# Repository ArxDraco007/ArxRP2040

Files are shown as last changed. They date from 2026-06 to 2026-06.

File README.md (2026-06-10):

# ArxRP2040 - A Custom DevBoard

## Why did I make this project?
Most devboards have limited usability. They don't fit every project. Therefore, it is best that there exists a board that is most customizable, adhering to the purposes that most projects need. This is a basic, very compact devboard that has 24 GPIO pins. This project gives a very good idea of the wiring of devboards and the parts needed to make your own.
This project can be built upon, adding additional parts, extending it, and adding the design.

## Pictures - 






## How to make it?
Follow the schematic and wire the PCB.
Use the Image Converter in KiCad to convert your images to footprints to decorate your PCB.
Download the MicroPython .uf2 file for the RP2040 from micropython.org. Hold the BOOT button (SW1) while plugging in the USB. The board appears as a USB drive. Drag and drop the .uf2 file onto it. Use Thonny IDE or any serial terminal to upload main.py
Start by applying flux to the pads on the footprint where you'll be soldering. Tin one of the pads with a small amount of solder, then carefully place your component onto the footprint. Touch your iron to the tinned pad to reflow it and tack the component in place, then let go with your tweezers once it's sitting right. Move to the opposite pad and solder it properly to the component. Finally, go back to your first pad and add a bit more solder to make sure you've got a solid joint.

## Zine!
zine

## BOM 
| Name | Purpose | Quantity | Total Cost (USD) | Link | Distributor |
|---|---|---|---|---|---|
| RP2040 | Main MCU (QFN-56) | 1 | $1.00 | [Raspberry Pi]([https://www.digikey.in/en/products/detail/raspberry-pi/SC0914/13624793](https://www.raspberrypi.com/products/rp2040/)) | Raspberry Pi |
| MCP1700x-330xxTT | 3.3V 250mA LDO regulator (SOT-23) | 1 | $0.50 | [DigiKey](https://www.digikey.in/en/products/detail/microchip-technology/MCP1700T-3302E-TT/652676) | DigiKey |
| W25Q16JVZPIQ | 16Mbit QSPI NOR Flash (WSON-8) | 1 | $0.80 | [DigiKey](https://www.digikey.in/en/products/detail/winbond-electronics/W25Q16JVZPIQ/6193781) | DigiKey |
| USB-C Receptacle 14P | HRO TYPE-C-31-M-12 or equiv | 1 | $0.50 | [Hubtronics](https://hubtronics.in/usb-c-female-port?srsltid=AfmBOop8mfonTlbqSHLuMisYp1z4lderBX-p3EpFVBi8DrW3sMfJKgY2) | Hubtronics |
| Conn_01x20 header | 2.54mm 20-pin single row (J3 and J4) | 2 | $1.00 | [Mouser](https://www.mouser.in/ProductDetail/Amphenol-FCI/67996-420HLF?qs=QKvFUfBIyQIvQWWcVN8Heg%3D%3D) | Mouser |
| Conn_01x03 header | 2.54mm 3-pin SWD debug header (J2) | 1 | $0.20 | [Robu](https://robu.in/product/ds1021-03-1x3sf11-b-connfly-1x3-pin-2-54mm-pin-header-single-row-press-fit-type/) | Robu |
| SW_Push tactile switch | BOOT/RUN button (SW1) | 1 | $0.20 | [Digikey](https://www.digikey.in/en/products/detail/alps-alpine/SKRKAEE020/19529176) | Digikey |
| Crystal 12MHz GND24 | SMD 4-pad crystal 3.2x2.5mm (Y1) | 1 | $0.50 | [ETStore](https://www.etstore.in/products/d10953) | ETStore |
| Resistor 5.1K 0402 | CC pull-downs for USB-C (R1, R2) | 2 | $0.10 | [Mouser](https://www.mouser.in/ProductDetail/Vishay-Dale/RCC04025K10FKED?qs=Imq1NPwxi76qRPANg4q4sQ%3D%3D) | Mouser |
| Resistor 27R 0402 | USB D+/D− series resistors (R3, R4) | 2 | $0.10 | [Robu](https://robu.in/product/erj2rkf27r0x-panasonic-smd-chip-resistor-27-ohm-%c2%b1-1-100-mw-0402-1005-metric-thick-film-precision/) | Robu |
| Resistor 1K 0402 | General purpose (R5, R6) | 2 | $0.10 | [Mouser](https://www.mouser.in/ProductDetail/Vishay/CRCW04021K00FHEDP?qs=Vd2sgofiCLVNiwckQwwOyw%3D%3D) | Mouser |
| Resistor 10K 0402 | Pull-up (R7) | 1 | $0.05 | [Robu](https://robu.in/product/rc0402fr-0710kl-yageo-smd-chip-resistor-10-kohm-%C2%B1-1-200-mw-0402-1005-metric-thick-film-pulse-proof-high-power-pack-of-10/) | Robu |
| Capacitor 1uF 0402 | Bulk decoupling (C1, C10) | 2 | $0.20 | [Robu](https://robu.in/product/1uf-capacitor-smdc-0402-pack-of-50/) | Robu |
| Capacitor 0.1uF 0402 | Decoupling (C2–C9, C11, C12, C17) | 11 | $0.55 | [Robu](https://robu.in/product/0402yd104kat2a-kyocera-avx-smd-multilayer-ceramic-capacitor-0-1-%C2%B5f-16-v-0402-1005-metric-%C2%B1-10-x5r-avx-0402-mlcc/) | Robu |
| Capacitor 10uF 0603 | LDO bulk caps (C13, C14) | 2 | $0.30 | [Robu](https://robu.in/product/10uf-10000nf-50v-capacitor-0603-smd-package-pack-of-5/) | Robu |
| Capacitor 33pF 0402 | Crystal load caps (C15, C16) | 2 | $0.20 | [Robu](https://robu.in/product/mc0402n330j500ct-murata-smd-multilayer-ceramic-capacitor-33-pf-50-v-0402-1005-metric-%C2%B1-5-c0g-np0-mc/) | Robu |
| PCB 2-layer ENIG | JLCPCB, 5 boards | 5 | $18.00 | [JLCPCB](https://jlcpcb.com/) | JLCPCB |
| **Total** | | | **$24.30** | | |

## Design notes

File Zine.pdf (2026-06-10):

# ARXRP2040

# ARYAN INDIA GAVASKAR

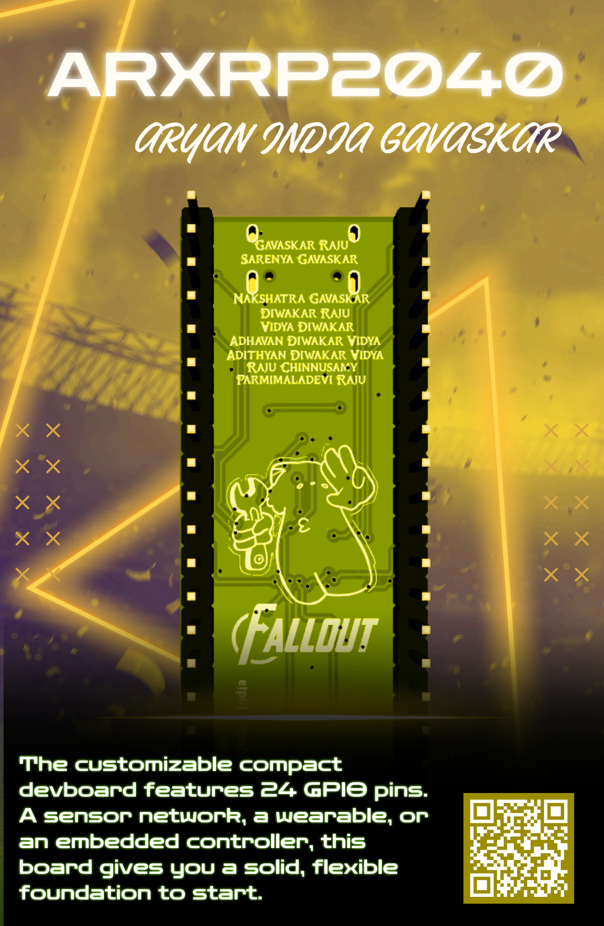
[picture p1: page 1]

The customizable compact
devboard features 24 GPIO pins. A sensor network, a wearable, or an embedded controller, this board gives you a solid, flexible foundation to start.

The customizable compact
devboard features 24 GPIO pins. A sensor network, a wearable, or an embedded controller, this board gives you a solid, flexible foundation to start.

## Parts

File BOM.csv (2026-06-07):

Name | Purpose | Quantity | Total Cost (USD) | Link | Distributor
RP2040 | Main MCU (QFN-56) | 1 | $1.00 | https://www.raspberrypi.com/products/rp2040/ | Raspberry Pi
MCP1700x-330xxTT | 3.3V 250mA LDO regulator (SOT-23) | 1 | $0.50 | https://www.digikey.in/en/products/detail/microchip-technology/MCP1700T-3302E-TT/652676 | DigiKey
W25Q16JVZPIQ | 16Mbit QSPI NOR Flash (WSON-8) | 1 | $0.80 | https://www.digikey.in/en/products/detail/winbond-electronics/W25Q16JVZPIQ/6193781 | DigiKey
USB-C Receptacle 14P | HRO TYPE-C-31-M-12 or equiv | 1 | $0.50 | https://hubtronics.in/usb-c-female-port | Hubtronics
Conn_01x20 header | 2.54mm 20-pin single row (J3 and J4) | 2 | $1.00 | https://www.mouser.in/ProductDetail/Amphenol-FCI/67996-420HLF?qs=QKvFUfBIyQIvQWWcVN8Heg%3D%3D | Mouser
Conn_01x03 header | 2.54mm 3-pin SWD debug header (J2) | 1 | $0.20 | https://robu.in/product/ds1021-03-1x3sf11-b-connfly-1x3-pin-2-54mm-pin-header-single-row-press-fit-type/ | Robu
SW_Push tactile switch | BOOT/RUN button (SW1) | 1 | $0.20 | https://www.digikey.in/en/products/detail/alps-alpine/SKRKAEE020/19529176 | Digikey
Crystal 12MHz GND24 | SMD 4-pad crystal 3.2x2.5mm (Y1) | 1 | $0.50 | https://www.etstore.in/products/d10953 | ETStore
Resistor 5.1K 0402 | CC pull-downs for USB-C (R1 R2) | 2 | $0.10 | https://www.mouser.in/ProductDetail/Vishay-Dale/RCC04025K10FKED?qs=Imq1NPwxi76qRPANg4q4sQ%3D%3D | Mouser
Resistor 27R 0402 | USB D+/D- series resistors (R3 R4) | 2 | $0.10 | https://robu.in/product/erj2rkf27r0x-panasonic-smd-chip-resistor-27-ohm | Robu
Resistor 1K 0402 | General purpose (R5 R6) | 2 | $0.10 | https://www.mouser.in/ProductDetail/Vishay/CRCW04021K00FHEDP?qs=Vd2sgofiCLVNiwckQwwOyw%3D%3D | Mouser
Resistor 10K 0402 | Pull-up (R7) | 1 | $0.05 | https://robu.in/product/rc0402fr-0710kl-yageo-smd-chip-resistor-10-kohm | Robu
Capacitor 1uF 0402 | Bulk decoupling (C1 C10) | 2 | $0.20 | https://robu.in/product/1uf-capacitor-smdc-0402-pack-of-50/ | Robu
Capacitor 0.1uF 0402 | Decoupling (C2-C9, C11, C12, C17) | 11 | $0.55 | https://robu.in/product/0402yd104kat2a-kyocera-avx-smd-multilayer-ceramic-capacitor | Robu
Capacitor 10uF 0603 | LDO bulk caps (C13 C14) | 2 | $0.30 | https://robu.in/product/10uf-10000nf-50v-capacitor-0603-smd-package-pack-of-5/ | Robu
Capacitor 33pF 0402 | Crystal load caps (C15 C16) | 2 | $0.20 | https://robu.in/product/mc0402n330j500ct-murata-smd-multilayer-ceramic-capacitor-33-pf | Robu
PCB 2-layer ENIG | JLCPCB, 5 boards | 5 | $18.00 | https://jlcpcb.com/ | JLCPCB
Total |  |  |  | $24.30

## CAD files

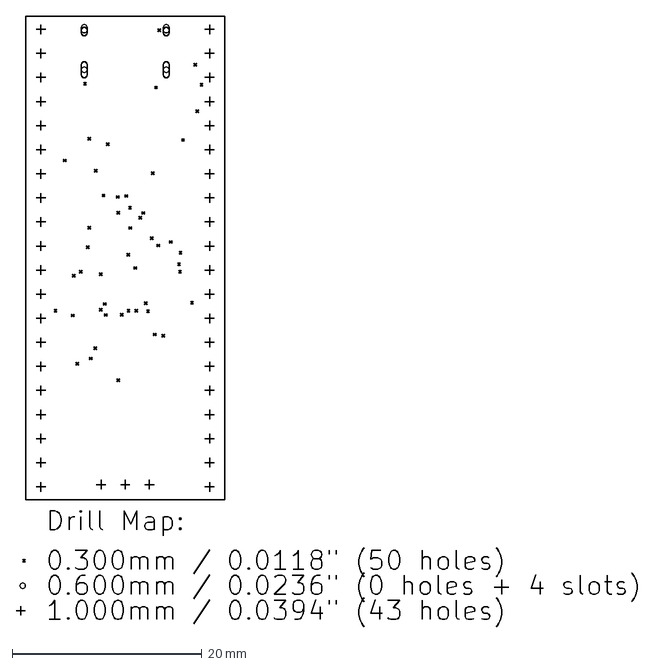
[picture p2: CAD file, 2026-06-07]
Production Files/Drill Files/ArxRP2040Devboard-PTH-drl_map.dxf
65.5 x 64.4 mm

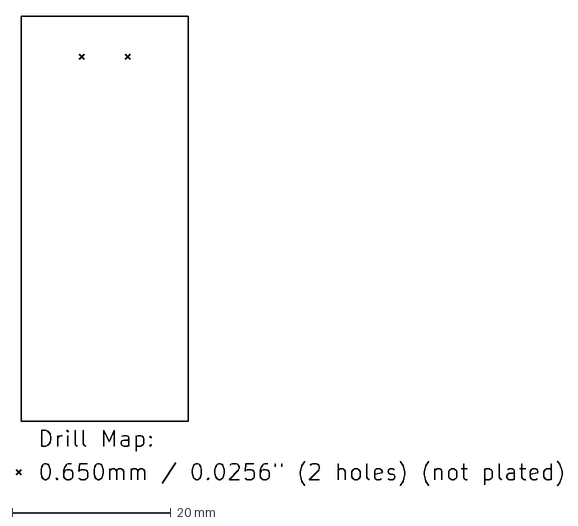
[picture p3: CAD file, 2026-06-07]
Production Files/Drill Files/ArxRP2040Devboard-NPTH-drl_map.dxf
68.8 x 59.1 mm

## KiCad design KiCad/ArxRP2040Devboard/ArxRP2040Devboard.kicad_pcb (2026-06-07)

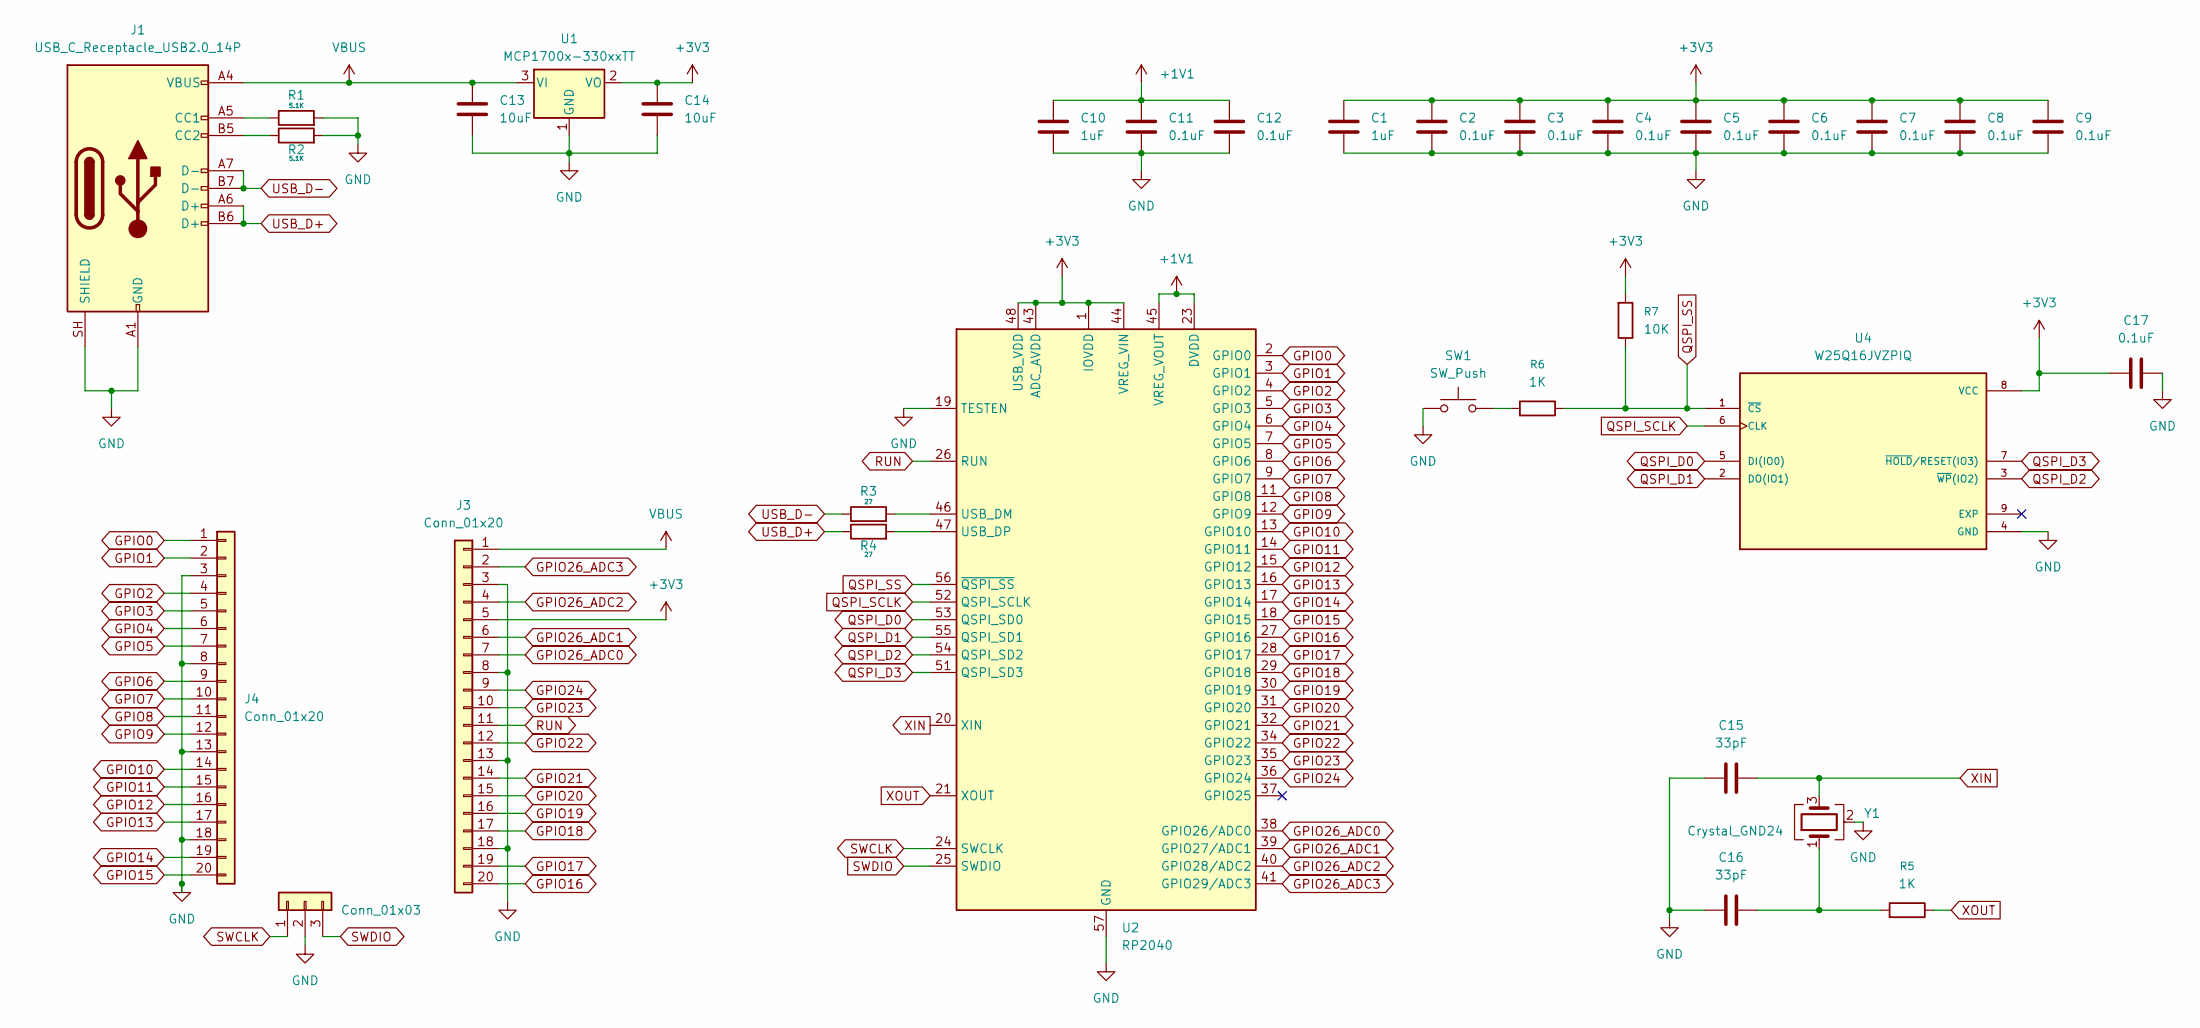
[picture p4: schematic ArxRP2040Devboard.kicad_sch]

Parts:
C1, C10: 1uF; C_0402_1005Metric
C2, C3, C4, C5, C6, C7, C8, C9, C11, C12, C17: 0.1uF; C_0402_1005Metric
C13, C14: 10uF; C_0603_1608Metric
C15, C16: 33pF; C_0402_1005Metric
J1: USB_C_Receptacle_USB2.0_14P; USB_C_Receptacle_HRO_TYPE-C-31-M-12
J2: Conn_01x03; PinHeader_1x03_P2.54mm_Vertical
J3, J4: Conn_01x20; PinHeader_1x20_P2.54mm_Vertical
R1, R2: 5.1K; R_0402_1005Metric
R3, R4: 27; R_0402_1005Metric
R5, R6: 1K; R_0402_1005Metric
R7: 10K; R_0402_1005Metric
SW1: SW_Push; SW_Push_SPST_NO_Alps_SKRK
U1: MCP1700x-330xxTT; SOT-23
U2: RP2040; QFN-56-1EP_7x7mm_P0.4mm_EP3.2x3.2mm
U4: W25Q16JVZPIQ; Winbond_USON-8-1EP_3x2mm_P0.5mm_EP0.2x1.6mm
Y1: Crystal_GND24; Crystal_SMD_3225-4Pin_3.2x2.5mm_HandSoldering

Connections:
+1V1: C10.1, C11.1, C12.1, U2.23 (DVDD), U2.45 (VREG_VOUT), U2.50 (DVDD)
+3V3: C1.1, C2.1, C3.1, C4.1, C5.1, C6.1, C7.1, C8.1, C9.1, C14.1, C17.1, J3.5, R7.1, U1.2 (VO), U2.1 (IOVDD), U2.10 (IOVDD), U2.22 (IOVDD), U2.33 (IOVDD), U2.42 (IOVDD), U2.43 (ADC_AVDD), U2.44 (VREG_VIN), U2.48 (USB_VDD), U2.49 (IOVDD), U4.8 (VCC)
GND: C1.2, C2.2, C3.2, C4.2, C5.2, C6.2, C7.2, C8.2, C9.2, C10.2, C11.2, C12.2, C13.2, C14.2, C15.1, C16.1, C17.2, J1.A1 (GND), J1.A12 (GND), J1.B1 (GND), J1.B12 (GND), J1.SH (SHIELD), J2.2, J3.3, J3.8, J3.13, J3.18, J4.3, J4.8, J4.13, J4.18, R1.2, R2.2, SW1.1, U1.1 (GND), U2.19 (TESTEN), U2.57 (GND), U4.4 (GND), Y1.2 (G), Y1.4 (G)
GPIO0: J4.1, U2.2 (GPIO0)
GPIO1: J4.2, U2.3 (GPIO1)
GPIO2: J4.4, U2.4 (GPIO2)
GPIO3: J4.5, U2.5 (GPIO3)
GPIO4: J4.6, U2.6 (GPIO4)
GPIO5: J4.7, U2.7 (GPIO5)
GPIO6: J4.9, U2.8 (GPIO6)
GPIO7: J4.10, U2.9 (GPIO7)
GPIO8: J4.11, U2.11 (GPIO8)
GPIO9: J4.12, U2.12 (GPIO9)
GPIO10: J4.14, U2.13 (GPIO10)
GPIO11: J4.15, U2.14 (GPIO11)
GPIO12: J4.16, U2.15 (GPIO12)
GPIO13: J4.17, U2.16 (GPIO13)
GPIO14: J4.19, U2.17 (GPIO14)
GPIO15: J4.20, U2.18 (GPIO15)
GPIO16: J3.20, U2.27 (GPIO16)
GPIO17: J3.19, U2.28 (GPIO17)
GPIO18: J3.17, U2.29 (GPIO18)
GPIO19: J3.16, U2.30 (GPIO19)
GPIO20: J3.15, U2.31 (GPIO20)
GPIO21: J3.14, U2.32 (GPIO21)
GPIO22: J3.12, U2.34 (GPIO22)
GPIO23: J3.10, U2.35 (GPIO23)
GPIO24: J3.9, U2.36 (GPIO24)
GPIO26_ADC0: J3.7, U2.38 (GPIO26/ADC0)
GPIO26_ADC1: J3.6, U2.39 (GPIO27/ADC1)
GPIO26_ADC2: J3.4, U2.40 (GPIO28/ADC2)
GPIO26_ADC3: J3.2, U2.41 (GPIO29/ADC3)
unnamed: C16.2, R5.1, Y1.1
unnamed: J1.A5 (CC1), R1.1
unnamed: J1.B5 (CC2), R2.1
unnamed: R6.1, SW1.2
unnamed: R3.2, U2.46 (USB_DM)
unnamed: R4.2, U2.47 (USB_DP)
QSPI_D0: U2.53 (QSPI_SD0), U4.5 (DI(IO0))
QSPI_D1: U2.55 (QSPI_SD1), U4.2 (DO(IO1))
QSPI_D2: U2.54 (QSPI_SD2), U4.3 (~WP(IO2))
QSPI_D3: U2.51 (QSPI_SD3), U4.7 (~HOLD/RESET(IO3))
QSPI_SCLK: U2.52 (QSPI_SCLK), U4.6 (CLK)
QSPI_SS: R6.2, R7.2, U2.56 (~QSPI_SS), U4.1 (~CS)
RUN: J3.11, U2.26 (RUN)
SWCLK: J2.1, U2.24 (SWCLK)
SWDIO: J2.3, U2.25 (SWDIO)
USB_D+: J1.A6 (D+), J1.B6 (D+), R4.1
USB_D-: J1.A7 (D-), J1.B7 (D-), R3.1
VBUS: C13.1, J1.A4 (VBUS), J1.A9 (VBUS), J1.B4 (VBUS), J1.B9 (VBUS), J3.1, U1.3 (VI)
XIN: C15.2, U2.20 (XIN), Y1.3
XOUT: R5.2, U2.21 (XOUT)

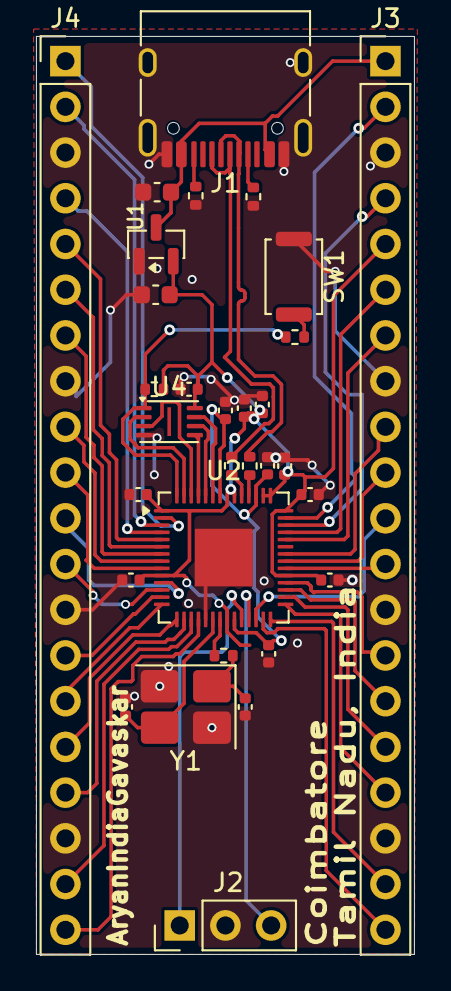
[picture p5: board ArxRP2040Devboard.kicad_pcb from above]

Board: 2 copper layers, 21.0 x 51.0 mm, 31 parts (0 on the bottom side), 52 nets.

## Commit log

2026-05-05 More connections
    [ArxRP2040Devboard.kicad_sch]
2026-05-05 KiCad wiring
    [ArxRP2040Devboard.kicad_sch]
2026-05-14 Schematic update
    [ArxRP2040Devboard.kicad_sch]
2026-06-07 PCB Designed!!!!!
    [ArxRP2040Devboard.kicad_pcb, ArxRP2040Devboard.kicad_sch]
2026-06-09 gerber includes the position stuff
    [ArxRP2040Devboard.kicad_sch]
